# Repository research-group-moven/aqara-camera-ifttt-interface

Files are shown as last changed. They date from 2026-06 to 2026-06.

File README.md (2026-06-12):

# Aqara camera IFTTT interface

The Aqara Camera Hub G3 offers AI-driven features such as face or pet detection. Unfortunately, these events cannot be used as triggers in IFTTT (at least in Europe). This project provides a workaround by making use of the camera's built-in IR functionality.

After setting up an automation in the Aqara Home app, the camera sends an IR signal when an AI event occurs (e.g. a specified face is detected). The IR sensor of this device receives the signal, and the ESP32 calls an IFTTT webhook in response, effectively bridging the Aqara ecosystem with any IFTTT-connected service.

> **Prerequisites:** Aqara Home App, IFTTT pro account

## How it works

The Aqara Home app allows the camera to imitate a TV remote control and send infrared signals. This project uses a virtual LG TV remote, where each number button (0–9) corresponds to a different AI event. The IR codes for these buttons use command values 16–25 (an LG-specific encoding), which the ESP32 decodes back to 0–9 before constructing the IFTTT webhook URL.

This allows up to 10 different AI events to trigger separate IFTTT applets.

## Setup

To use the interface you need the Aqara Home App and an IFTTT pro account to enable webhooks.

### Virtual TV remote control in Aqara Home App
1. Open the Aqara Home app and navigate to your camera.
2. Tap **Infrared Remote Control** at the bottom of the camera interface.
3. Add a new remote control and select **TV → LG**. LG is required as each brand uses unique IR codes and this project is built around LG's encoding.
4. Confirm the connection test and follow the on-screen instructions.

### Infrared Remote Control Sensor
Create a plain text file named `wifi.txt` on a MicroSD card with the following format:

```
WiFi-name,WiFi-password,IFTTT-event-prefix,IFTTT-key
```

| Field | Description |
|---|---|
| `WiFi-name` | Your WiFi network name (SSID) |
| `WiFi-password` | Your WiFi password |
| `IFTTT-event-prefix` | A prefix for your IFTTT event names, e.g. `my_trigger_` |
| `IFTTT-key` | Your IFTTT Webhook API key (found at `https://maker.ifttt.com/use/YOUR_KEY_HERE`) |

**Example:**
```
MyNetwork,secret123,my_trigger_,abc123xyz
```

### Camera AI automations in Aqara Home

1. Go to **Automation** in the Aqara Home app and tap the **+** button.
2. Select your camera under **Accessories** as the trigger (**When**) and choose an AI event (e.g. *Specified face detected*).
3. As the action (**Then**), select the virtual LG remote and assign a button between **0 and 9**.

#### IFTTT setup

1. Create a new applet with **Webhooks** ("Receive a web request") as the trigger.
2. Name the event using your chosen prefix followed by a number, e.g. `my_trigger_1`.
3. Choose any service as the output (**Then**).

## List of parts

| Name | Description |
|---|---|
| Wemos D1 Mini ESP32 | Microcontroller board |
| MicroSD Card Module | SPI-based MicroSD card reader |
| MicroSD Card (≤32GB) | Stores the credentials file |
| VS1838B / OS-1838B IR Receiver | Infrared signal sensor |
| PCB | Carrier board for all modules |
| Connectors | For connecting modules to the PCB |
| USB cable | Powers the microcontroller |

## Carrier board for all modules

### Circuit

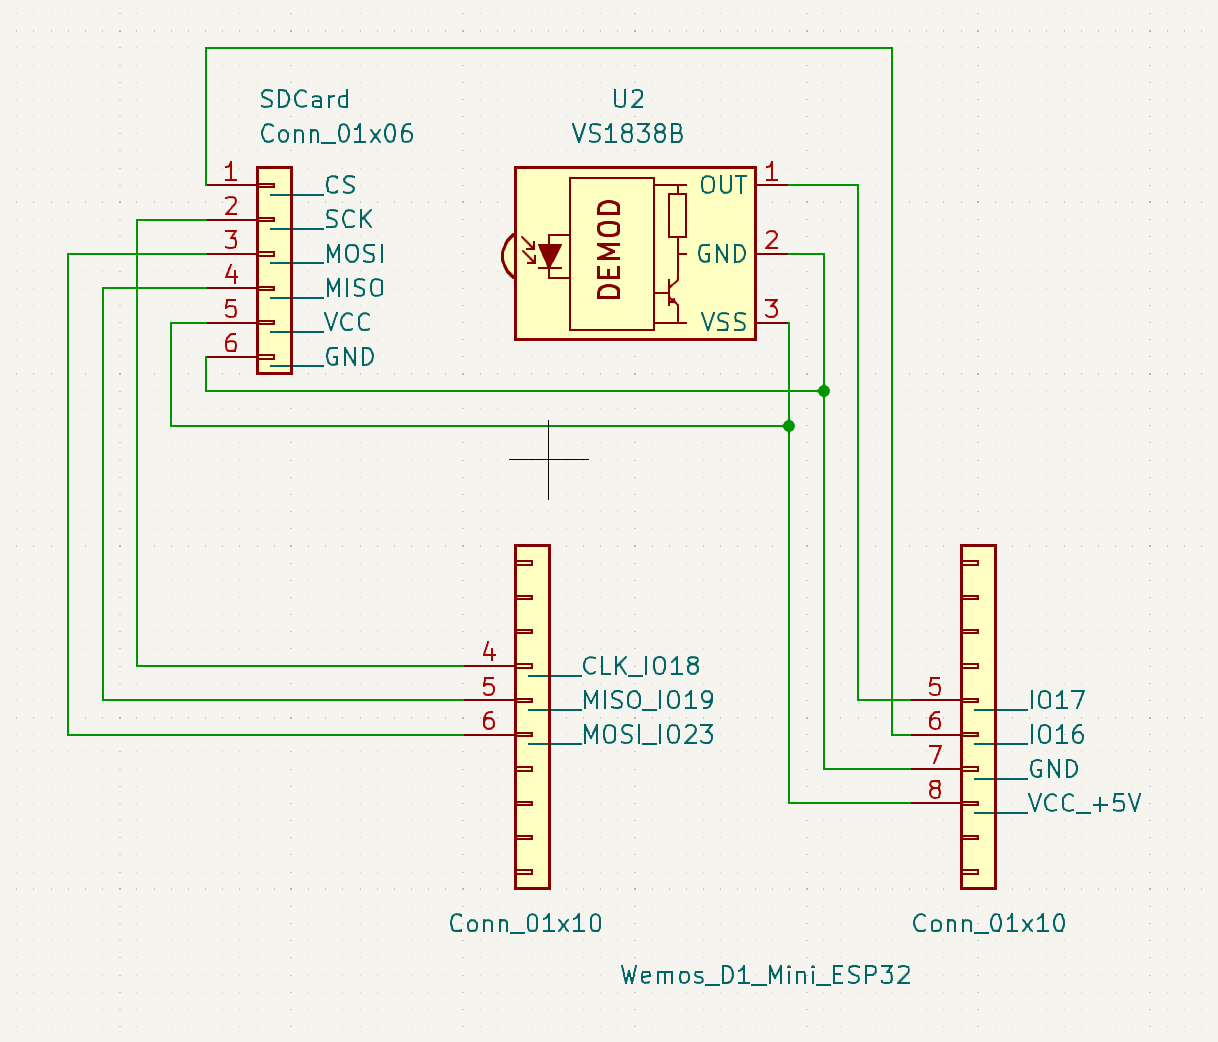
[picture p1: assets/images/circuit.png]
Circuit of the carrier board for the modules


### Handmade PCB

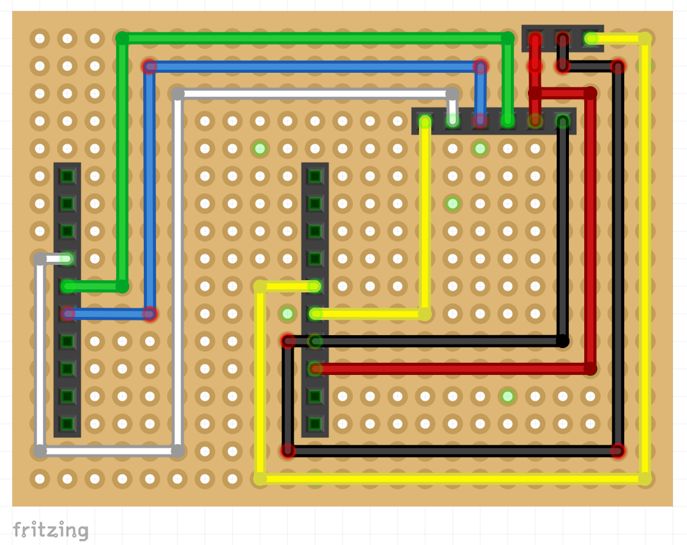
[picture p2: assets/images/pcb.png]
Handmade PCB


## Todo

- [ ] Improve code
    - [ ] Become independent of specifically simulating the IR signals of an LG TV (IR Address 4 and number buttons 16–25 instead of 0–9)
- [ ] Create PCB for production

## License

This project is licensed under the GPL-3.0 License.
© Till Maria Jürgens / MOVEN Research Group, Rhine-Waal University of Applied Sciences

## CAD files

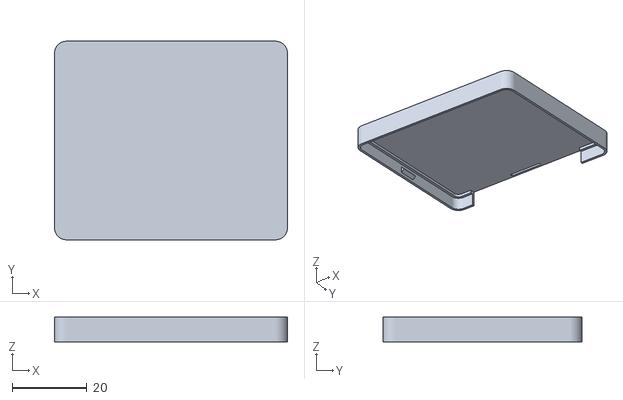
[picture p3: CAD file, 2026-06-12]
hardware/box/top.stl
62.4 x 53.2 x 6.60

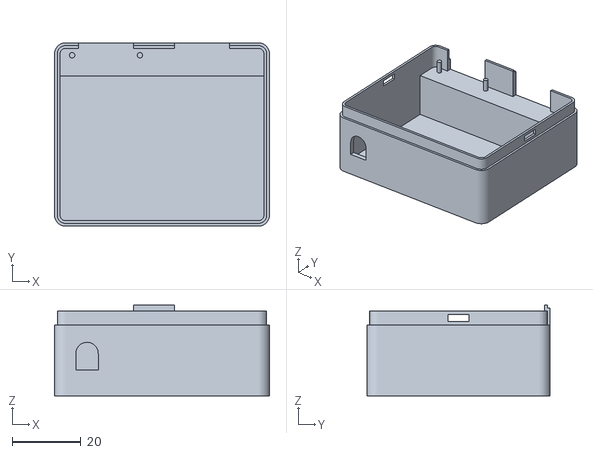
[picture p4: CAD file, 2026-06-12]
hardware/box/bottom.stl
62.4 x 53.2 x 26.4

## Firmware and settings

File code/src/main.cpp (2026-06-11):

/**
 * Aqara camera IFTTT interface
 * Name: aqara-camera-ifttt-interface
 * Purpose: This interface allows using the AI functions of the Aqara Camera, such as face detection, as a trigger for IFTTT applets.
 * 
 * @author Till Maria Jürgens
 * @version 0.1.1
 * 
 * This project is developed and used in a student project by the MOVEN research group at the chair of Design Digital Media, Rhine-Waal University of Applied Sciences. More information: https://www.sustainabilitybydesign.net/moven
*/

// include libraries
#include <Arduino.h>
#include <SPI.h>
#include <SD.h>
#include <WiFi.h>
#include <IRremote.hpp>

// ID of virtual device, 4 stands for a LG TV
#define IR_REMOTE_ID 4

// vars
String ssid;
String password;
String ifttt_key;
String ifttt_event_prefix;

// pins
#define SD_PIN          16
#define IR_RECEIVE_PIN  17

// IFTTT connection
#define HOST "maker.ifttt.com"
#define PORT 80


/*
Pseudo-decoding of commands from the number buttons 0–9 that are coded as 16–25 in the case of an LG TV.
*/
String decode_command(int command) {
  int command_decoded = command - 16;
  return String(command_decoded);
}

/*
Call IFTTT trigger with JSON data
*/
void send_webhook(int address, int command) {
  WiFiClient client;

  if (address != IR_REMOTE_ID) {
    return;
  }

  if (!client.connect(HOST, PORT)) {
    return;
  }

  // construct JSON
  String jsonString = "";
  jsonString += "{\"value1\":\"";
  jsonString += String(address);
  jsonString += "\",\"value2\":\"";
  jsonString += String(command);
  jsonString += "\",\"value3\":\"";
  jsonString += decode_command(command);
  jsonString += "\"}";
  int jsonLength = jsonString.length();  
  String lenString = String(jsonLength);

  // construct POST request
  String postString = "";
  postString += "POST /trigger/";
  postString += ifttt_event_prefix + decode_command(command);
  postString += "/with/key/";
  postString += ifttt_key;
  postString += " HTTP/1.1\r\n";
  postString += "Host: maker.ifttt.com\r\n";
  postString += "Content-Type: application/json\r\n";
  postString += "Content-Length: ";
  postString += lenString + "\r\n";
  postString += "\r\n";
  postString += jsonString;
  postString += "\r\n";

  Serial.println(postString);

  client.print(postString);
  delay(500);
  client.stop();
}

void setup() {
  Serial.begin(115200);
  pinMode(LED_BUILTIN, OUTPUT);
  delay(1000);

  /*
  Init SD card
  and get WiFi and IFTTT credentials
  */
  Serial.print("Initializing SD card...");
  if (!SD.begin(SD_PIN)) {
    Serial.println("initialization failed!");
    while (1);
  }
  Serial.println("initialization done.");
  
  // read file
  File file = SD.open("/wifi.txt");
  if(!file){
    Serial.println("Failed to open file");
    while (1);
  }

  // parse credentials, format "ssid,password,ifttt_key"
  String content = "";
  while(file.available()){
      content += (char)file.read();
  }
  file.close();
  int firstComma  = content.indexOf(',');
  int secondComma = content.indexOf(',', firstComma + 1);
  int thirdComma = content.indexOf(',', secondComma + 1);
  ssid = content.substring(0, firstComma);
  password = content.substring(firstComma + 1, secondComma);
  ifttt_event_prefix = content.substring(secondComma + 1, thirdComma);
  ifttt_key = content.substring(thirdComma + 1);
  ifttt_key.trim();
  
  /*
  Init WiFi
  and connect
  */
  Serial.print("[WiFi] Connecting to ");
  Serial.println(ssid);

  WiFi.begin(ssid, password);

  // will try for about 10 seconds (20x 500ms)
  int tryDelay = 500;
  int numberOfTries = 20;
  bool wifiConnected = false;

  while (true) {
    switch (WiFi.status()) {
      case WL_NO_SSID_AVAIL: Serial.println("[WiFi] SSID not found"); break;
      case WL_CONNECT_FAILED:
        Serial.println("[WiFi] Failed - WiFi not connected!");
        break;
      case WL_CONNECTION_LOST: Serial.println("[WiFi] Connection was lost"); break;
      case WL_SCAN_COMPLETED:  Serial.println("[WiFi] Scan is completed"); break;
      case WL_DISCONNECTED:    Serial.println("[WiFi] WiFi is disconnected"); break;
      case WL_CONNECTED:
        Serial.println("[WiFi] WiFi is connected!");
        Serial.print("[WiFi] IP address: ");
        Serial.println(WiFi.localIP());
        wifiConnected = true;
        break;
      default:
        Serial.print("[WiFi] WiFi Status: ");
        Serial.println(WiFi.status());
        break;
    }
    if (wifiConnected) break;
    delay(tryDelay);

    if (numberOfTries <= 0) {
      Serial.print("[WiFi] Failed to connect to WiFi!");
      WiFi.disconnect();
      break;
    } else {
      numberOfTries--;
    }
  }

  if (!wifiConnected) {
    while (true) {
      digitalWrite(LED_BUILTIN, HIGH);
      delay(1000);
      digitalWrite(LED_BUILTIN, LOW);
      delay(1000);
    }
  }
  
  /*
  Init IrReceiver
  */
  IrReceiver.begin(IR_RECEIVE_PIN, ENABLE_LED_FEEDBACK);
}

void loop() {
  if (IrReceiver.decode()) {
    Serial.print("test: ");
    Serial.print(IrReceiver.decodedIRData.address);
    Serial.print(" # ");
    Serial.println(IrReceiver.decodedIRData.command);
    IrReceiver.resume(); // early enable receiving of the next IR frame
    if (IrReceiver.decodedIRData.flags & IRDATA_FLAGS_IS_REPEAT) { // prevent multiple signals in short time
      Serial.println(F("Repeat received. Do nothing and wait for next input."));
    } else {
      send_webhook(IrReceiver.decodedIRData.address, IrReceiver.decodedIRData.command);
    }
  }
  
  delay(10);
}

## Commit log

2026-06-12 Added circuit
    [aqara-camera-ifttt-interface.kicad_sch]
2026-06-12 Added stl of box
    [bottom.stl, top.stl]
